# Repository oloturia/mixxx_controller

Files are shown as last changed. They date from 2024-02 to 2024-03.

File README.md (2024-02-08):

A simple project that transform an Arduino Leonardo (or similar boards based on ATmega32u4) in a mixing console for open source Mixxx DJ software. To compile, you'll need MIDIUSB and EncoderButton libraries. Both are downloadable from the official Arduino IDE's library manager.

After uploading the sketch and connecting the controls, you'll have to "train" Mixxx to recognize the various sliders and knobs: click "Learning Wizard" and then follow the instructions. Some of the commands aren't selectable from the interface, you'll need to use the drop down menu to select them (i.e. "scroll up/down the library"). An example configuration is in the folder of the same name. You have to copy the .xml into /home/<user>/.mixxx/controllers/ folder.

Be aware that the controller needs to be plugged in before starting Mixxx. If you enabled the debug, you have to open a serial console to start the device.

At the moment it supports these kinds of controls:
- Analog controls (knobs, sliders) need to be connected to an analog input.
- Rotary encoders, clk should be connected to an interrupt pin, dt to a digital input.
- Buttons (also on top of rotary encoders) need to be connected to digital input.

Buttons feature single and long press. They could have also two states that toggle (i.e. start/stop, etc.).
Analog controls have three "magnetic" positions: around 0, 1023 and middle (user defined) the reading has more stickyness (user definable). If you see that Mixxx's control is not in the middle when the potentiometer is at its half, alter the middle "magnetic" position.
They have also a dead zone that filters small variations in the readings. If you see that the controls are oscillating, increase the dead zone.

There are two experimental improvements:
- In the "console" folder there is a PCB made in Kicad, ready to be printed. Some of the footprints come from Digi-Key/digikey-kicad-library. The example configuration is trained on this PCB.
- If you need more analog controls, there is a version that features a multiplexer. I've tested with three potentiometers and worked, I've not tested it yet for a full console anyway.

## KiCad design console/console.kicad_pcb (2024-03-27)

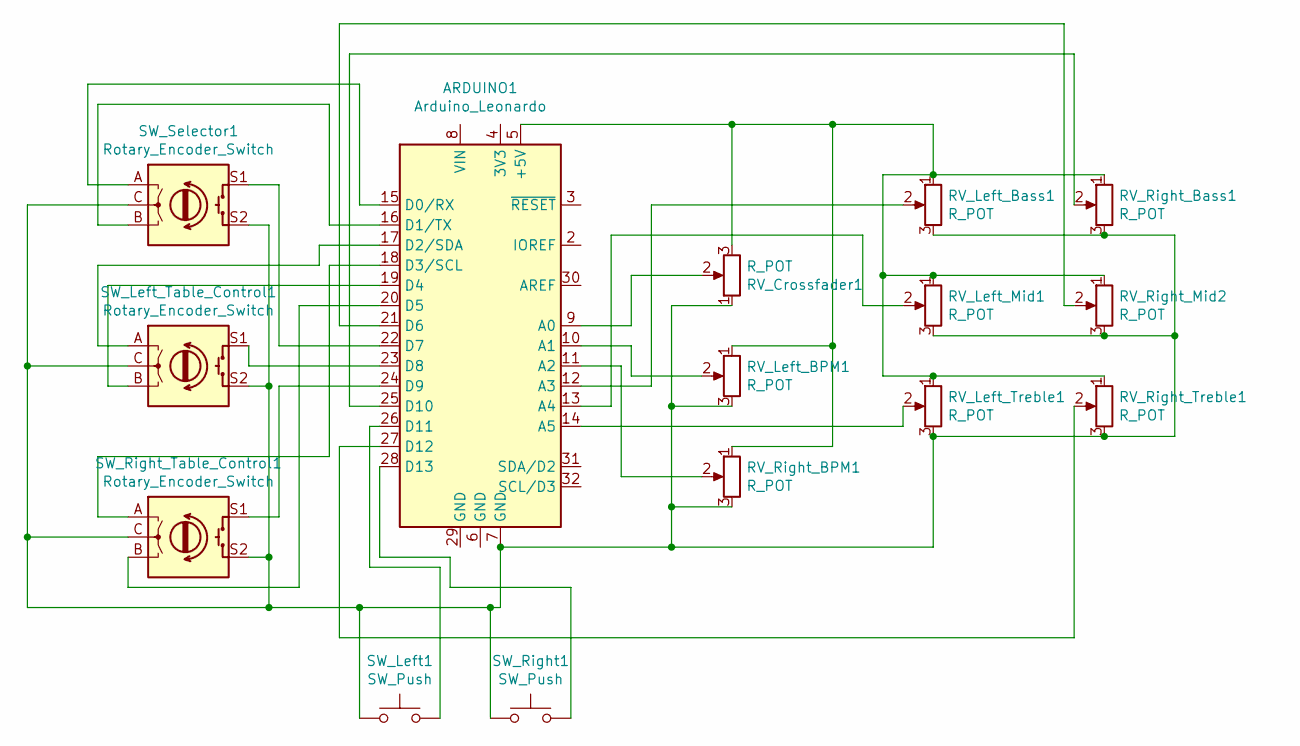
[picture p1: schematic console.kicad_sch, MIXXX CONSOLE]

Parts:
ARDUINO1: Arduino_Leonardo; Arduino_UNO_R3
RV_Crossfader1: R_POT; Potentiometer_Bourns_PTA6043_Single_Slide
RV_Left_BPM1: R_POT; Potentiometer_Bourns_PTA4543_Single_Slide
RV_Left_Bass1: R_POT; Potentiometer_Bourns_PTV09A-1_Single_Vertical
RV_Left_Mid1: R_POT; Potentiometer_Bourns_PTV09A-1_Single_Vertical
RV_Left_Treble1: R_POT; Potentiometer_Bourns_PTV09A-1_Single_Vertical
RV_Right_BPM1: R_POT; Potentiometer_Bourns_PTA4543_Single_Slide
RV_Right_Bass1: R_POT; Potentiometer_Bourns_PTV09A-1_Single_Vertical
RV_Right_Mid2: R_POT; Potentiometer_Bourns_PTV09A-1_Single_Vertical
RV_Right_Treble1: R_POT; Potentiometer_Bourns_PTV09A-1_Single_Vertical
SW_Left1: SW_Push; D6R90F2LFS
SW_Left_Table_Control1: Rotary_Encoder_Switch; XDCR_PEC11R-4215F-S0024
SW_Right1: SW_Push; D6R90F2LFS
SW_Right_Table_Control1: Rotary_Encoder_Switch; XDCR_PEC11R-4215F-S0024
SW_Selector1: Rotary_Encoder_Switch; XDCR_PEC11R-4215F-S0024

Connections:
unnamed: ARDUINO1.5 (+5V), RV_Crossfader1.3, RV_Left_BPM1.1, RV_Left_Bass1.1, RV_Left_Mid1.1, RV_Left_Treble1.1, RV_Right_BPM1.1, RV_Right_Bass1.1, RV_Right_Mid2.1, RV_Right_Treble1.1
unnamed: ARDUINO1.7 (GND), RV_Crossfader1.1, RV_Left_BPM1.3, RV_Left_Bass1.3, RV_Left_Mid1.3, RV_Left_Treble1.3, RV_Right_BPM1.3, RV_Right_Bass1.3, RV_Right_Mid2.3, RV_Right_Treble1.3, SW_Left1.1, SW_Left_Table_Control1.C, SW_Left_Table_Control1.S2, SW_Right1.1, SW_Right_Table_Control1.C, SW_Right_Table_Control1.S2, SW_Selector1.C, SW_Selector1.S2
unnamed: ARDUINO1.9 (A0), RV_Crossfader1.2
unnamed: ARDUINO1.10 (A1), RV_Left_BPM1.2
unnamed: ARDUINO1.11 (A2), RV_Right_BPM1.2
unnamed: ARDUINO1.12 (A3), RV_Left_Bass1.2
unnamed: ARDUINO1.13 (A4), RV_Left_Mid1.2
unnamed: ARDUINO1.14 (A5), RV_Left_Treble1.2
unnamed: ARDUINO1.15 (D0/RX), SW_Selector1.A
unnamed: ARDUINO1.16 (D1/TX), SW_Selector1.B
unnamed: ARDUINO1.17 (D2/SDA), SW_Left_Table_Control1.A
unnamed: ARDUINO1.18 (D3/SCL), SW_Right_Table_Control1.A
unnamed: ARDUINO1.19 (D4), SW_Left_Table_Control1.B
unnamed: ARDUINO1.20 (D5), SW_Right_Table_Control1.B
unnamed: ARDUINO1.21 (D6), RV_Right_Mid2.2
unnamed: ARDUINO1.22 (D7), SW_Selector1.S1
unnamed: ARDUINO1.23 (D8), SW_Left_Table_Control1.S1
unnamed: ARDUINO1.24 (D9), SW_Right_Table_Control1.S1
unnamed: ARDUINO1.25 (D10), RV_Right_Bass1.2
unnamed: ARDUINO1.26 (D11), SW_Left1.2
unnamed: ARDUINO1.27 (D12), RV_Right_Treble1.2
unnamed: ARDUINO1.28 (D13), SW_Right1.2

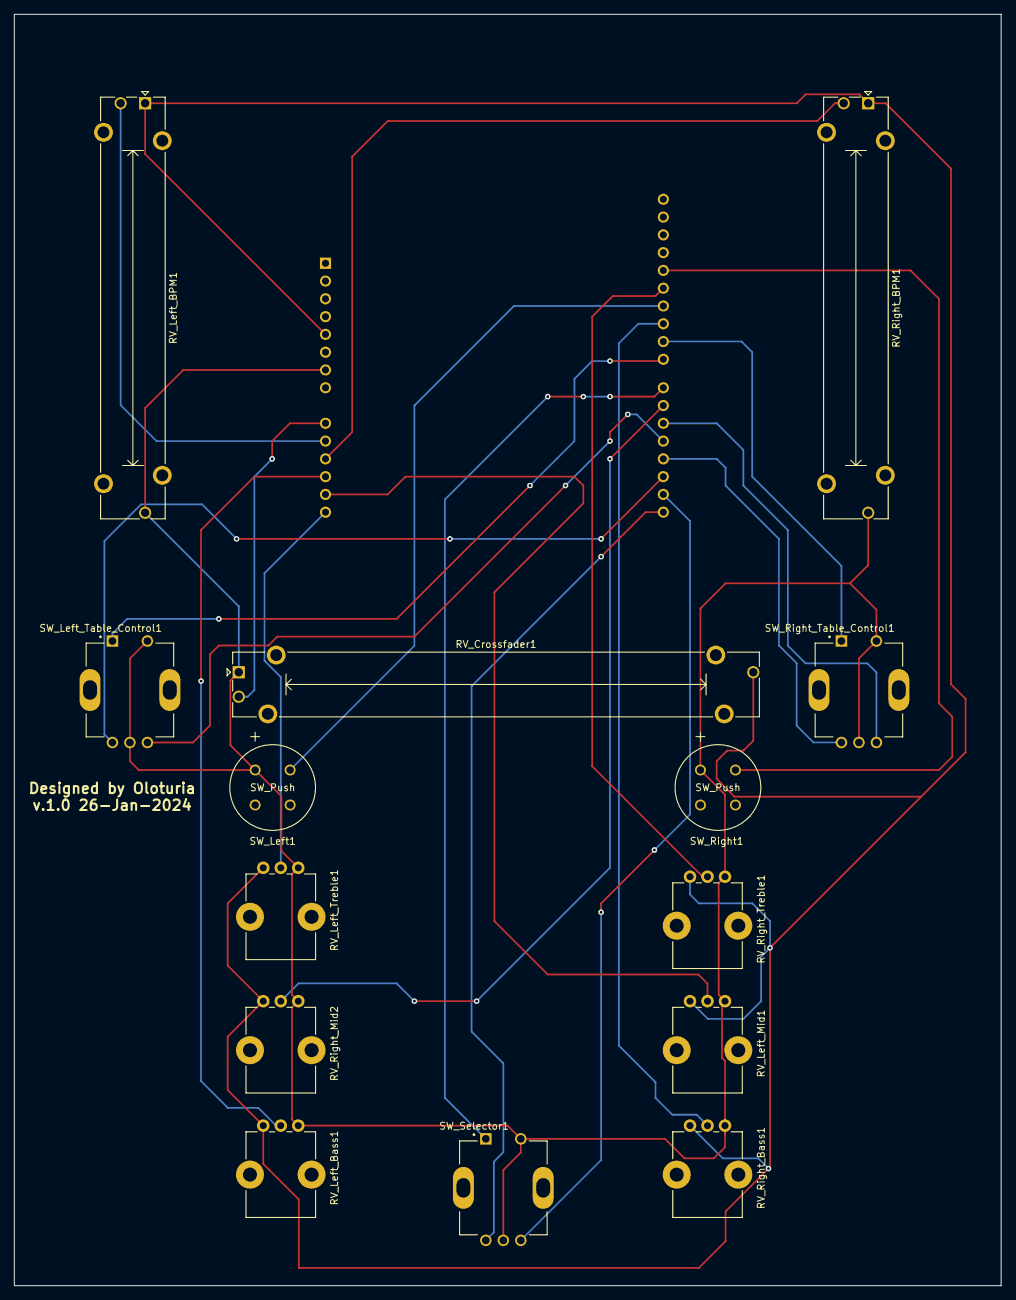
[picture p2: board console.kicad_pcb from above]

Board: 2 copper layers, 141.0 x 181.6 mm, 15 parts (1 on the bottom side), 22 nets.

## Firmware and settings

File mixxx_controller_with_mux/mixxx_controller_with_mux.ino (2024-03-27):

#include "Controllers.h"

/* This is a sketch that it transforms your Arduino Leonardo or Leonardo like (i.e. boards with atmega32u4) in a MIDI console for interfacing
 * with Mixxx (https://mixxx.org). Perhaps you can also use an UNO but you have to sacrifice some pins in order to add a MIDI interface to your Arduino.
 * Once you have flashed the board, you have to train Mixxx in Preferences/Controllers menu.
 * Remember to plug the Arduino before launching Mixxx, otherwise it won't be detected.
 * 
 * This software is released under the Unlicense (see LICENSE for more info).
 * 
 * This version allow the use of multiplexers for analog inputs, this feature is not tested yet.
 * If you have doubts, use mixxx_controller.ino instead.
 * 
 * Last revision 27-mar-2024
 */

/* You can alter some library wide parameters in Controllers.h
 * DEBUG enables serial printing of MIDI messages
 * DEAD_ZONE contains the smallest increment that the control must have to trigger the effect.
 * STICKYNESS is a deazone that lies around extreme positions (0-1023) and the middle of readings.
 * TIME_INTERVAL is the time, in ms, needed for a long press
*/

// Pin definition
// Analog knobs and sliders
/* Connect linear potentiometers (sliders and knobs) to Analog Inputs on your board.
 * On Leonardo, from A0 to A5 are on the left (with USB on top)
 * A6, A7, A8, A9, A10, A11 are digital pins:
 *  4,  6,  8,  9,  10,  12.
 *  
 * Change the first value accordingly, the last one is the MIDI effect that is sent to
 * Mixxx, every control needs to have a unique number.
 * 
 * MID-DEADZONE is the middle of the controller. Usually is 511, but it's trimmable.
*/

// Define every control as AnalogControl(PIN,EFFECT,MID-DEADZONE)
AnalogControl analog_controls[] = {
//  AnalogControl(A0,7,520),

};

int active_analog_controls = sizeof(analog_controls)/sizeof(analog_controls[0]);

// Rotary encoders
/* Rotary Encorders need two pins. 
 * clk should be an interrupt. On Leonardo interrupts are on pin 0, 1, 2, 3 and 7.
 * dt are digital pins
 * effect and effect+1 must be unique
 * the +1 is reserved for anticlockwise  
 */ 

// Define every control as {EncoderButton(CLK,DT), EFFECT}
RotaryEncoderControl rotary_encoders[] = {
  //{EncoderButton(2,4),10},
  
};

const int active_encoders = sizeof(rotary_encoders)/sizeof(rotary_encoders[1]);

// Digital buttons
/* Digital buttons are connected to a digital pin. If you use toggle, long press or long press toggle rembember that the MIDI message byte has to be unique.
 * toggle effect and long toggle effect (for long presses) send two different messages for odd and even strokes.
 * If effect is 0 the toggle, long press or long press toggle is disabled.
 */

// Define every control as DigitalButton(PIN,PRESS EFFECT, PRESS TOGGLE EFFECT (0=disabled), LONG PRESS EFFECT, LONG PRESS TOGGLE EFFECT (0=disabled)
DigitalButton buttons[] = {
//  DigitalButton( 9,14,0, 0, 0),

};
const int active_buttons = sizeof(buttons)/sizeof(buttons[0]);

//Callback function for the encoders
void eb_Encoder(EncoderButton& eb) {
 int inc = eb.increment();
 if (inc > 0) {
  controlChange(1,eb.userId()+1,1);
 } else {
  controlChange(1,eb.userId(),1);
 }
 MidiUSB.flush();
}

/* Multiplexers allow multiple analog inputs using only 1 analog input and 4 digital outputs.
 * pinSIG is the input pin for the signal, pinS0 to pinS3 are the digital outputs that select
 * the analog channel that will be connected with SIG.
 * 
 */

// Define every Multiplexer as 
// (SIGNAL PIN, S0, S1, S2, S3, EFFECT (array of 16), MIDDLE DEADZONE (array of 16) ) 

int mux0[16] = { 10, 11, 12, 13, 14, 15, 16, 17, 18, 19, 20, 21, 22, 23, 24, 25};
int midzones0[16] = {520,520,520,520,520,520,520,520,520,520,520,520,520,520,520,520};

Mux mux_inputs[] = {
  Mux(A0, 4, 5, 6, 7, mux0, midzones0)
};

const int active_mux_inputs = sizeof(mux_inputs)/sizeof(mux_inputs[0]);


void setup() {
  #ifdef DEBUG
    while(!Serial);
    Serial.begin(115200);
    Serial.println("RDY");
  #endif

  for (int i = 0; i < active_encoders; i++) {
    rotary_encoders[i].rotary_encoder.setUserId(rotary_encoders[i].effect);
    rotary_encoders[i].rotary_encoder.setEncoderHandler(eb_Encoder);
  }   
}

void loop() {

  // Analog controls check
  for (int i = 0; i < active_analog_controls; i++) {
    analog_controls[i].checkStatus();
  }

  // Buttons check
  for (int i = 0; i < active_buttons; i++) {
    buttons[i].checkStatus();
  }
  
  // Rotary encoders check
  for (int i = 0; i < active_encoders; i++) {
    rotary_encoders[i].rotary_encoder.update();
  }
  
  // Analog signal from multiplexer check.
  for (int i = 0; i < active_mux_inputs; i++) {
    for (int act = 0; act < 16; act++) {
      mux_inputs[i].checkStatus(act);
    }
  }
 
}

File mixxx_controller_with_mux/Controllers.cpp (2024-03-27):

#include "Controllers.h"

// MIDI

// First parameter is the event type (0x09 = note on, 0x08 = note off).
// Second parameter is note-on/note-off, combined with the channel.
// Channel can be anything between 0-15. Typically reported to the user as 1-16.
// Third parameter is the note number (48 = middle C).
// Fourth parameter is the velocity (64 = normal, 127 = fastest).

// First parameter is the event type (0x0B = control change).
// Second parameter is the event type, combined with the channel.
// Third parameter is the control number number (0-119).
// Fourth parameter is the control value (0-127).

void noteOn(byte channel, byte pitch, byte velocity) {
  midiEventPacket_t noteOn = {0x09, 0x90 | channel, pitch, velocity};
  #ifdef DEBUG
    Serial.print("Note on:");
    Serial.print(channel);
    Serial.print(",");
    Serial.print(pitch);
    Serial.print(",");
    Serial.println(velocity);
  #endif
  MidiUSB.sendMIDI(noteOn);
}

void noteOff(byte channel, byte pitch, byte velocity) {
  midiEventPacket_t noteOff = {0x08, 0x80 | channel, pitch, velocity};
   #ifdef DEBUG
    Serial.print("Note off:");
    Serial.print(channel);
    Serial.print(",");
    Serial.print(pitch);
    Serial.print(",");
    Serial.println(velocity);
  #endif
  MidiUSB.sendMIDI(noteOff);
}

void controlChange(byte channel, byte control, byte value) {
  midiEventPacket_t event = {0x0B, 0xB0 | channel, control, value};
  #ifdef DEBUG
    Serial.print("Control change:");
    Serial.print(channel);
    Serial.print(",");
    Serial.print(control);
    Serial.print(",");
    Serial.println(value);
  #endif
  MidiUSB.sendMIDI(event);
}

// Constructor and methods for analog controls and buttons (encoders use a different library)

AnalogControl::AnalogControl(int pin, byte effect, int middle) {
  this->pin = pin;
  this->effect = effect;
  this->middle = middle;
  pinMode(pin,INPUT);
}

void AnalogControl::checkStatus() {
  value = analogRead(pin);
  if (value < 0+STICKYNESS){
      value = 0;
  } else if (value > 1023-STICKYNESS) {
      value = 1023;
  } else if (value > middle-STICKYNESS && value < middle+STICKYNESS) {
      value = middle;
  }
  if ( abs(value - prev_value) > DEAD_ZONE ){
    controlChange(1,effect, map(value,0,1023,0,127) );
    prev_value = value;
    MidiUSB.flush();
  }
}

DigitalButton::DigitalButton(int pin, byte effect, byte effect_toggle, byte effect_long, byte effect_long_toggle) {
  this->effect = effect;
  this->effect_toggle = effect_toggle;
  this->effect_long = effect_long;
  this->effect_long_toggle = effect_long_toggle;
  this->pin = pin;
  pinMode(pin,INPUT_PULLUP);
}


void DigitalButton::checkStatus() {
  if (digitalRead(pin) == LOW && pressed == false) {
      pressed = true;
      long_pressed = false;
      debounce = millis();
    }
    if (pressed && (millis() - debounce <= 10) && digitalRead(pin) == HIGH) {
      pressed = false;
      return;
    }
    if (pressed && (millis() - debounce > 10) && digitalRead(pin) == HIGH) {
        if (long_pressed == true) {
          long_pressed = false;
        } else if (effect_toggle == 0) {
          controlChange(1,effect,1);
        } else if (toggled) {
          controlChange(1,effect,1);
          toggled = false;
        } else {
          controlChange(1,effect_toggle,1);
          toggled = true;
        }
      MidiUSB.flush();        
      pressed = false;
    }
    if (pressed && (millis() - debounce > LONG_INTERVAL) && (digitalRead(pin) == LOW) && (long_pressed == false)) {
      long_pressed = true;
      if (effect_long_toggle == 0) {
        controlChange(1,effect_long,1);
      } else if (long_toggled) {
        controlChange(1,effect_long,1);
        long_toggled = false;     
      } else {
        controlChange(1,effect_long_toggle,1);
        long_toggled = true;              
      }
      MidiUSB.flush();
    }
}

Mux::Mux(int pinSIG, int pinS0, int pinS1, int pinS2, int pinS3, int effects[16], int mid_deadzone[16]) {
  this->pinSIG = pinSIG;
  this->pinS0 = pinS0;
  this->pinS1 = pinS1;
  this->pinS2 = pinS2;
  this->pinS3 = pinS3;
  pinMode(pinSIG,INPUT);
  pinMode(pinS0,OUTPUT);
  pinMode(pinS1,OUTPUT);
  pinMode(pinS2,OUTPUT);
  pinMode(pinS3,OUTPUT);
  for (int i = 0; i < 16; i++) {
    this->effects[i] = effects[i];
    this->mid_deadzone[i] = effects[i];
  }
}

void Mux::checkStatus(byte selector){
  digitalWrite(pinS0, bitRead(selector,0));
  digitalWrite(pinS1, bitRead(selector,1));
  digitalWrite(pinS2, bitRead(selector,2));
  digitalWrite(pinS3, bitRead(selector,3));  
  int value = analogRead(pinSIG);

  if (value < STICKYNESS) {
    value = 0;
  } else if (value > 1023-STICKYNESS) {
    value = 1023;
  } else if (value > mid_deadzone-STICKYNESS && value < mid_deadzone+STICKYNESS) {
    value = mid_deadzone;
  }

  if (abs(value - prev_value[selector]) > DEAD_ZONE ) {
    byte midi_value = map(value,0,1023,0,127);
    controlChange(1,effects[selector],midi_value);
    #ifdef DEBUG
      Serial.print("Mux ");
      Serial.print(effects[selector]);
      Serial.print(", ");
      Serial.println(value);
    #endif
    prev_value[selector] = value;
    MidiUSB.flush();
  }
}

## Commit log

2023-07-28 working encoders
2023-08-03 added 3rd rotary encoder
2023-08-04 compacted encoders
2023-12-27 Added new features: - Dead zones for analog controllers, with stickyness on extreme values (0-1023) and middle (custom value, 512ish). - Separated values that need to be customized for every board (i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
2024-01-05 pcb initialized
    [console.kicad_pcb, console.sch]
2024-01-16 pcb in progress
    [console.sch]
2024-01-19 pcb init
    [console.kicad_pcb, console.sch]
2024-01-20 PCB complete, not tested yet
    [console.kicad_pcb, console.sch]
2024-01-26 added edges
    [console.kicad_pcb]
2024-01-26 error corrected, gerber files created
    [console-B_Cu.gbr, console-B_Mask.gbr, console-B_Paste.gbr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]
2024-01-27 corrected small error
    [console.kicad_pcb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]
2024-02-05 PCB tested, working
2024-03-27 updated kicad version, added gitignore
    [console.kicad_pcb, console.kicad_sch]

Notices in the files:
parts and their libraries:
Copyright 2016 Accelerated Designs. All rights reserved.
